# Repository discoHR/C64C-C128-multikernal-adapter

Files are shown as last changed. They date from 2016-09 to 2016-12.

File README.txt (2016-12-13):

C64C/C128 Switchless Multi-Kernal Adapter
27C512/27C256 ROM adapter for C64C and C128
https://github.com/discoHR/C64C-C128-multikernal-adapter
Designed by discoHR, based on Bwack's 24-pin adapter design.
(https://github.com/bwack/C64-Switchless-Multi-Kernal-27C256-adapter)
CERN OPEN HARDWARE LICENSE v1.2
http://www.ohwr.org/

It allows you to run either:
a) four kernals using a 27C512 (SJ1 open)
b) two kernals using a 27C256 (SJ1 closed)

Hold the restore key to enter the select mode. You will notice a fast flash
on the LED. Release the restore key when the flashing stops and press it
shortly as many times as you want to switch to the other kernals.
The LED colour will indicate which kernal is selected.
The C64 will reset to selected kernal shortly after you stop pressing the
restore key.

The Reset button (if present) behaves similar to the restore key but
unlike the restore key, the reset button is always in select mode.

There are two LED colour themes but due to hardware limitations, they don't
differ much. You can hold the restore key during power-on to toggle between
the two themes.

Theme #1:
2 kernals: yellow, blue
4 kernals: red, blue, green, cyan

Theme #2:
2 kernals: orange, magenta
4 kernals: red, magenta, lime, white

For R1, R2 and R3 you can use any value up to 12k (perhaps even more), depends
how bright you want the RGB LED.

Changelog:

Firmware udpates (PCB agnostic)

2016-10-23
- using sleep and IOC

PCB rev1.1 (final)

2016-10-02
- expanded the pcb a bit
- increased the distance between EPROM and connectors
- increased font sizes
- moved some texts to the bottom
- added CERN OHL and GitHub URL to the silkscreen
- finalized rev1.1

2016-09-30
- first version of firmware

2016-09-28
- swapped BLUE and GREEN signals to match the RGB LED pinout
- using 6.7k value for R1, R2 and R3

2016-09-19
- bumped resistor values significantly because the LED is still too bright at 6.7k
- increased the board size a bit and rerouted most of the traces

2016-09-18
- added license
- moved pin headers to the bottom where they belong
- using larger pads

PCB rev1.0 (final)

2016-09-17
- added board images and PDF with schematic
- minor aesthetic changes on the silk layer

2016-09-15
- removed R4
- rearranged signal-pin pairs to allow using weak pull-up for the solder jumper
- minor design changes
- improved routing
- fixed incorrectly connected switch
- moved everything from _tsilk to tNames layer

2016-09-14
- added NC next to unconnected pin
- initial commit

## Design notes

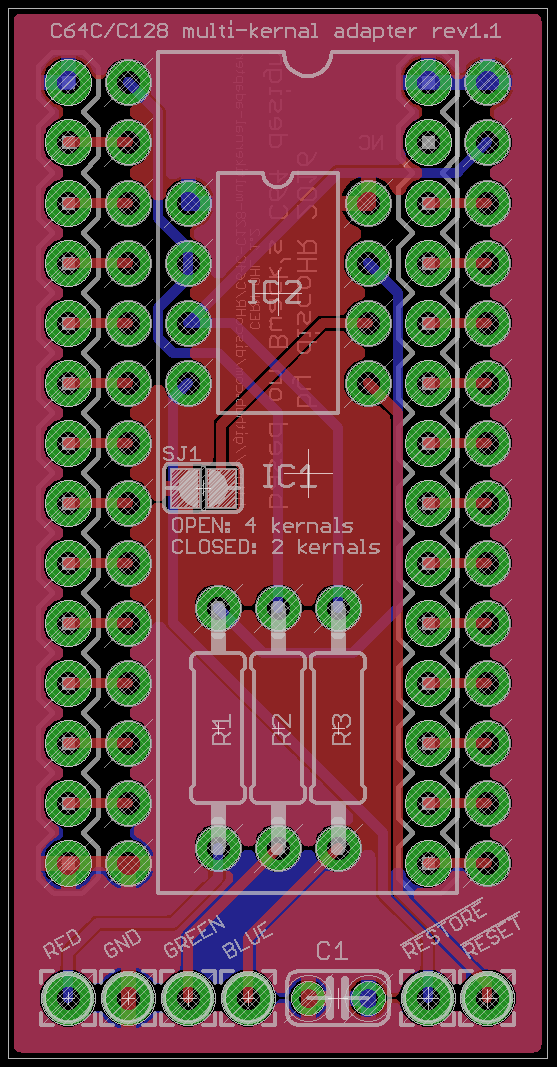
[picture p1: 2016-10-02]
C64C-C128-multikernal.png

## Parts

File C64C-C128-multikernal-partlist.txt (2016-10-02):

Partlist

Exported from C64C-C128-multikernal.sch at 02.10.2016. 12:00

EAGLE Version 7.6.0 Copyright (c) 1988-2016 CadSoft

Assembly variant: 

Part      Value                Device                     Package                      Library             Sheet

!RESET!                        2,15/1,0                   2,15/1,0                     wirepad             1
!RESTORE!                      2,15/1,0                   2,15/1,0                     wirepad             1
BLUE                           2,15/1,0                   2,15/1,0                     wirepad             1
C1        100n                 C-EU025-024X044            C025-024X044                 rcl                 1
GND                            2,15/1,0                   2,15/1,0                     wirepad             1
GREEN                          2,15/1,0                   2,15/1,0                     wirepad             1
IC1       27C256/512           IC-PACKAGE_EDIT_DIL28ROUND IC-PACKAGE_EDIT_DIL28SPECIAL c64switchless       1
IC2       MICROCHIP_PIC12F629P MICROCHIP_PIC12F629P       MICROCHIP_DIL8               c64switchless       1
J1                             M14                        1X14                         SparkFun-Connectors 1
J2                             M14                        1X14                         SparkFun-Connectors 1
R1        6.7k                 RCL_R-EU_0207/10           RCL_0207/10                  c64switchless       1
R2        6.7k                 RCL_R-EU_0207/10           RCL_0207/10                  c64switchless       1
R3        6.7k                 RCL_R-EU_0207/10           RCL_0207/10                  c64switchless       1
RED                            2,15/1,0                   2,15/1,0                     wirepad             1
SJ1                            SJ                         SJ                           jumper              1

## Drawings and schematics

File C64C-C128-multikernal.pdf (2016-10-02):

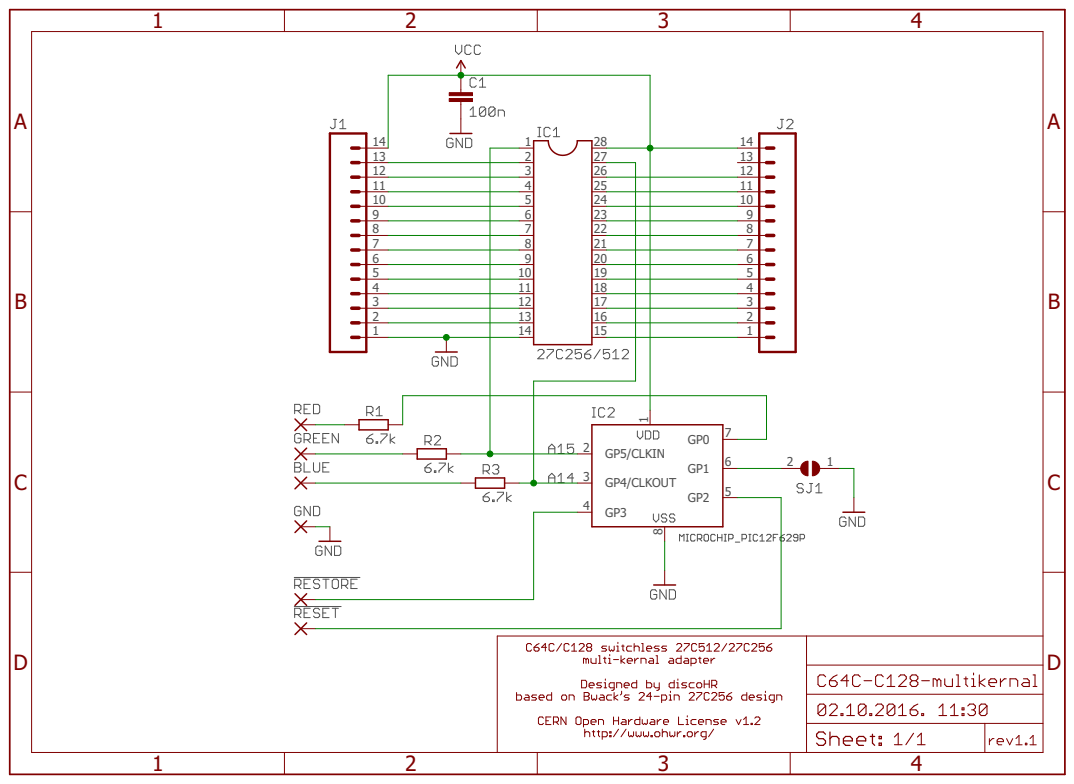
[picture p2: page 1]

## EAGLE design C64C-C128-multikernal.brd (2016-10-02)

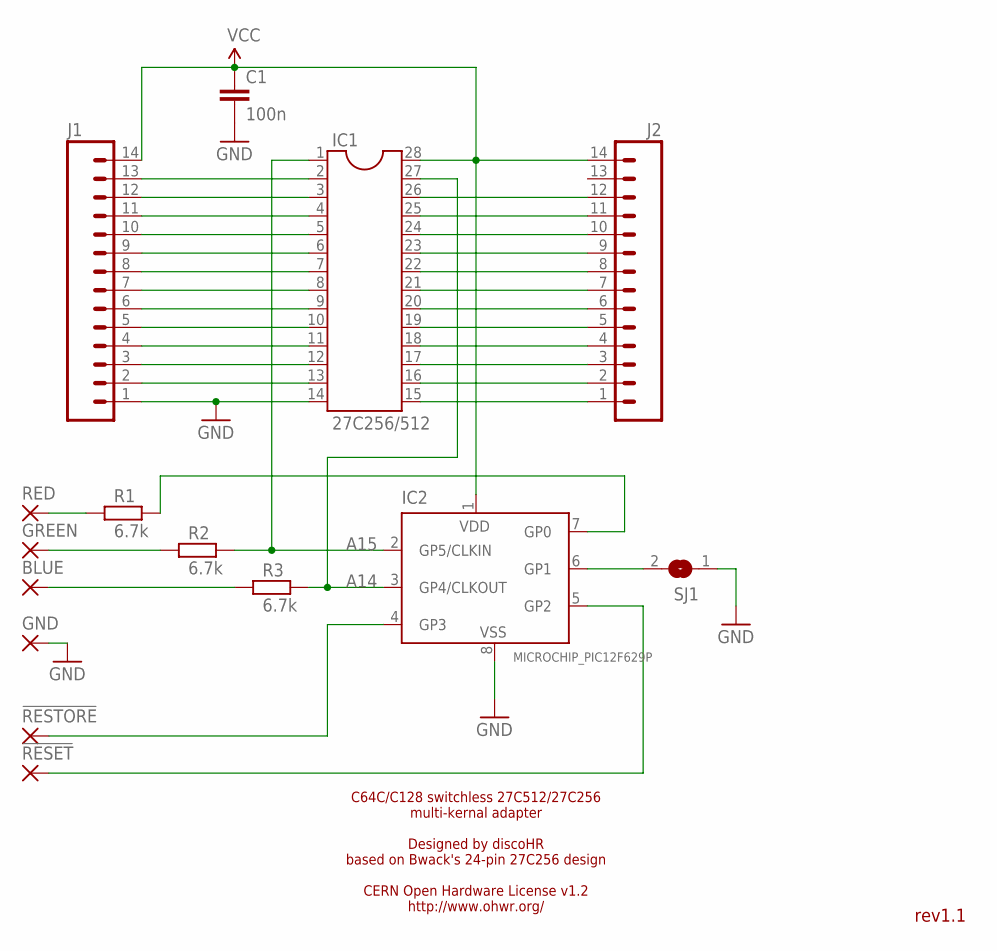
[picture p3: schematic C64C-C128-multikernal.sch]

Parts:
!RESET!: 2,15/1,0
!RESTORE!: 2,15/1,0
BLUE: 2,15/1,0
C1: 100n; C025-024X044
GND: 2,15/1,0
GREEN: 2,15/1,0
IC1: 27C256/512; IC-PACKAGE_EDIT_DIL28SPECIAL
IC2: MICROCHIP_PIC12F629P; MICROCHIP_DIL8
J1, J2: M14; 1X14
R1, R2, R3: 6.7k; RCL_0207/10
RED: 2,15/1,0
SJ1: SJ

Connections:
A14: IC1.27, IC2.3 (GP4/CLKOUT), R3.2
A15: IC1.1, IC2.2 (GP5/CLKIN), R2.2
GND: C1.2, GND.1, IC1.14, IC2.8 (VSS), J1.1, SJ1.1
unnamed: IC2.7 (GP0), R1.2
unnamed: R1.1, RED.1
unnamed: IC1.15, J2.1
unnamed: IC1.16, J2.2
unnamed: IC1.17, J2.3
unnamed: IC1.18, J2.4
unnamed: IC1.19, J2.5
unnamed: IC1.20, J2.6
unnamed: IC1.21, J2.7
unnamed: IC1.22, J2.8
unnamed: IC1.23, J2.9
unnamed: IC1.24, J2.10
unnamed: IC1.25, J2.11
unnamed: IC1.26, J2.12
unnamed: IC1.2, J1.13
unnamed: IC2.6 (GP1), SJ1.2
unnamed: IC1.3, J1.12
unnamed: IC1.4, J1.11
unnamed: IC1.5, J1.10
unnamed: IC1.6, J1.9
unnamed: IC1.7, J1.8
unnamed: IC1.8, J1.7
unnamed: IC1.9, J1.6
unnamed: IC1.10, J1.5
unnamed: IC1.11, J1.4
unnamed: IC1.12, J1.3
unnamed: IC1.13, J1.2
unnamed: !RESET!.1, IC2.5 (GP2)
unnamed: GREEN.1, R2.1
unnamed: BLUE.1, R3.1
unnamed: !RESTORE!.1, IC2.4 (GP3)
VCC: C1.1, IC1.28, IC2.1 (VDD), J1.14, J2.14

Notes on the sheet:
C64C/C128 switchless 27C512/27C256 multi-kernal adapter Designed by discoHR based on Bwack's 24-pin 27C256 design CERN Open Hardware License v1.2 http://www.ohwr.org/
rev1.1

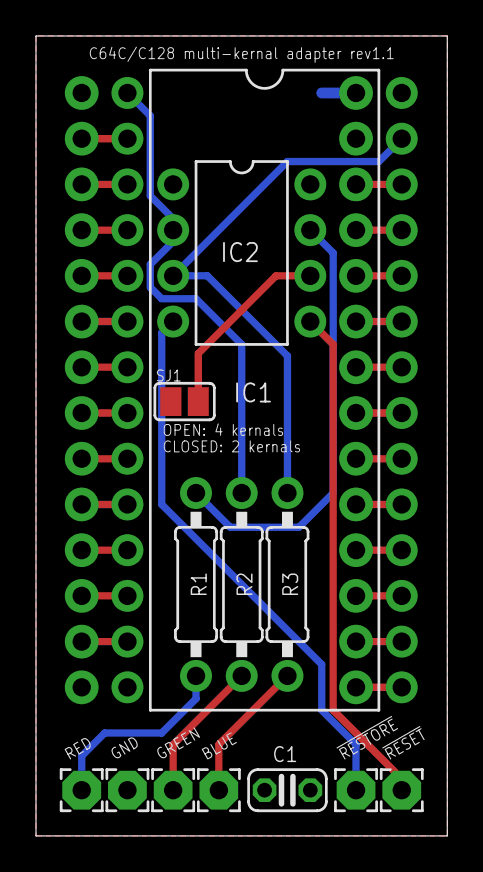
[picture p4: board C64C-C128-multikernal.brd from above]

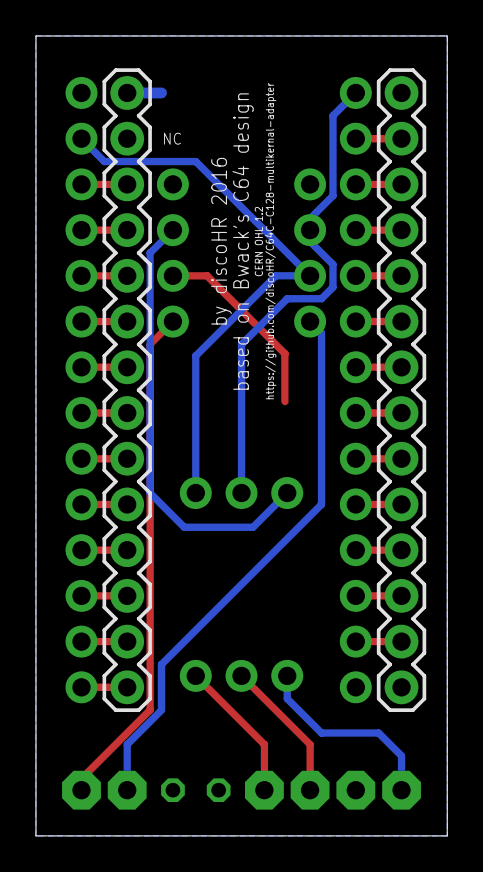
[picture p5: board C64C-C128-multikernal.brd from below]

Board: 2 copper layers, 22.8 x 44.4 mm, 15 parts (2 on the bottom side), 35 nets.

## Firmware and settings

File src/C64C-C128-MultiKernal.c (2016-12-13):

// Firmware for C64C/C128 multi-kernal adapter
// Coded by discoHR, based on Bwack's code for multi-kernal adapter for breadbin
// https://github.com/discoHR/C64C-C128-multikernal-adapter

// CONFIG
#pragma config FOSC = INTRCIO   // Oscillator Selection bits (INTOSC oscillator: I/O function on GP4/OSC2/CLKOUT pin, I/O function on GP5/OSC1/CLKIN)
#pragma config WDTE = OFF       // Watchdog Timer Enable bit (WDT disabled)
#pragma config PWRTE = OFF      // Power-Up Timer Enable bit (PWRT disabled)
#pragma config MCLRE = OFF      // GP3/MCLR pin function select (GP3/MCLR pin function is digital I/O, MCLR internally tied to VDD)
#pragma config BOREN = OFF      // Brown-out Detect Enable bit (BOD disabled)
#pragma config CP = OFF         // Code Protection bit (Program Memory code protection is disabled)
#pragma config CPD = OFF        // Data Code Protection bit (Data memory code protection is disabled)

// #pragma config statements should precede project file includes.
// Use project enums instead of #define for ON and OFF.

#define _XTAL_FREQ  4000000

#include <xc.h>
#include <pic12f629.h>

// inputs
#define SJ1         GPIObits.GP1
#define RESTORE_N   GPIObits.GP3

// outputs
#define RED_LED     GPIObits.GP0
#define A14         GPIObits.GP4
#define A15         GPIObits.GP5

// input/outputs
#define RESET_N     GPIObits.GP2

// EEPROM addresses used for configuration persistance
#define EEPROM_ADDR_KERNAL          0
#define EEPROM_ADDR_RED_INVERTED    2

#define KERNAL_MASK (SJ1 ? 3 : 1)
#define byte unsigned char

enum state_t {
    IDLE, SELECT
} state = IDLE;

byte buttonTimer, old_button;
byte kernalIndex, oldKernalIndex;
byte ignoreReset;
byte redInverted;

void DoReset(void) {
    RESET_N = 0;
    TRISIObits.TRISIO2 = 0; // pull INTRES_N low
    RED_LED ^= 1;
    __delay_ms(50);
    RED_LED ^= 1;
    __delay_ms(200);
    TRISIObits.TRISIO2 = 1; // release INTRES_N
    __delay_ms(250); // possible fix for double-reset cartridges
}

void SetKernal(byte index) {
    GPIO = (GPIO & 0x0f) | (index << 4);
    __delay_ms(20);
}

void SaveKernal(byte index) {
    // don't write unless necessary
    if (index != oldKernalIndex) {
        EEPROM_WRITE(EEPROM_ADDR_KERNAL, index);
        oldKernalIndex = index;
    }
}

void SetLED(void) {
    RED_LED = ((0 != kernalIndex) && redInverted) ^ ((buttonTimer & 2) ? 0 : 1);
}

void Init(void) {
    byte i;

    OPTION_REG = 0;
    WPUbits.WPU1 = 1;
    WPUbits.WPU2 = 1;
    WPUbits.WPU5 = 1;
    CMCON = 0x07; // digital IO
    TRISIO = 0b00101110;
    RESET_N = 1;
    RESTORE_N = 1;
    RED_LED = 0;
    __delay_ms(50);
    if (SJ1) {
        WPUbits.WPU5 = 0;
        TRISIO = 0b00001110;
    }
    kernalIndex = oldKernalIndex = EEPROM_READ(EEPROM_ADDR_KERNAL) & KERNAL_MASK;
    SetKernal(kernalIndex);
    redInverted = EEPROM_READ(EEPROM_ADDR_RED_INVERTED) & 1;
    DoReset();

    // IOCbits.IOC2 = IOCbits.IOC3 = 1;
    IOC = 0b00001100;       // GPIO interrupt-on-change for both inputs
    GPIE = 1;               // GPIO Interrupt enable, on
    GIE = 0;                // Global interrupt enable, off

    for (i = 0; i < 10; i++) {
        RED_LED = 0;
        __delay_ms(50);
        RED_LED = 1;
        __delay_ms(50);
    }

    __delay_ms(250); // ignore reset during power up
}

void main() {
    Init();

    // change the colour theme if user is holding the restore key on power-on
    if (!RESTORE_N) {
        redInverted ^= 1;
        EEPROM_WRITE(EEPROM_ADDR_RED_INVERTED, redInverted);
        // wait until restore key is released
        while (!RESTORE_N) {
            __delay_ms(100);
        }
    }

    // main loop
    for (;;) {
        SetLED();
        switch (state) {
            case IDLE:
                if (!RESTORE_N) {
                    ++buttonTimer;
                } else {
                    buttonTimer = 0;
                    SLEEP();
                    GPIF = 0;
                }
                if (buttonTimer > 15 || !RESET_N) {
                    // either the restore key was long-pressed or
                    // the reset button was short-pressed
                    state = SELECT;
                    old_button = buttonTimer = 0;
                    // ignore reset in the select state if it was the reset button
                    ignoreReset = !RESET_N;
                    RED_LED ^= 1;
                    __delay_ms(50);
                    RED_LED ^= 1;
                    __delay_ms(50);
                }
                break;

            case SELECT:
                if (!old_button && RESTORE_N && RESET_N) {
                    old_button = 1;
                } else if (old_button && (!RESTORE_N || !RESET_N)) {
                    old_button = ignoreReset = 0; // it's ok to reset after this
                    ++kernalIndex;
                    kernalIndex &= KERNAL_MASK;
                    SetKernal(kernalIndex);
                } else if (RESTORE_N && RESET_N) {
                    // both buttons released
                    ++buttonTimer;
                    if (buttonTimer > 30) {
                        // do the actual reset if needed and go back to idle state
                        old_button = 1;
                        if (!ignoreReset) {
                            DoReset();
                        }
                        SaveKernal(kernalIndex);
                        buttonTimer = 0;
                        state = IDLE;
                    }
                } else {
                    // at least one button is pressed
                    buttonTimer = 0;
                }
                break;

            default:
                // something is wrong, flash like crazy
                A14 = A15 = 0; // pull A14 and A15 low, makes red clearly visible
                RED_LED ^= 1;
                break;
        }
        __delay_ms(50);
    }
}

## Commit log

2016-09-14 added NC next to unconnected pin
2016-09-14 added NC next to the unconnected pin
    [c64-c128-4-kernals.brd]
2016-09-14 removed R4 rearranged signal-pin pairs to allow using weak pull-up for the solder jumper minor design changes improved routing
    [c64-c128-4-kernals.brd, c64-c128-4-kernals.sch]
2016-09-15 fixed incorrectly connected switch
    [c64-c128-4-kernals.brd, c64-c128-4-kernals.sch]
2016-09-15 moved everything from _tsilk to tNames layer
    [c64-c128-4-kernals.brd]
2016-09-17 added board images and PDF with schematic minor aesthetic changes on the silk layer
    [c64-c128-4-kernals.brd]
2016-09-18 added license
    [c64-c128-4-kernals.sch]
2016-09-18 moved pin headers to the bottom where they belong
    [c64-c128-4-kernals.brd, c64-c128-4-kernals.sch]
2016-09-18 using larger pads
    [c64-c128-4-kernals.brd, c64-c128-4-kernals.sch]
2016-09-18 added license to schematic
2016-09-19 bumped resistor values significantly because the LED is still too bright at 6.7k increased the board size a bit and rerouted most of the traces
    [c64-c128-4-kernals.brd, c64-c128-4-kernals.sch]
2016-09-28 swapped BLUE and GREEN signals to match the RGB LED pinout
2016-09-28 using 6.7k value for R1, R2 and R3
    [c64-c128-4-kernals.brd, c64-c128-4-kernals.sch]
2016-10-02 expanded the pcb a bit increased the distance between EPROM and connectors increased font sizes moved some texts to the bottom added CERN OHL and GitHub URL to the silkscreen finalized rev1.1
    [C64C-C128-multikernal.brd, C64C-C128-multikernal.sch]

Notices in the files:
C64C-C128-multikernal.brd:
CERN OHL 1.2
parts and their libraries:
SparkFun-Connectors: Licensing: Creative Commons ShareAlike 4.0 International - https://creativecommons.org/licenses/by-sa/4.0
